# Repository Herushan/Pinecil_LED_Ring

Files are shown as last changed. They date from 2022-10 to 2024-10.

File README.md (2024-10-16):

# Pinecil_LED_Ring
Finished board with ideal LED combination.
Finished on Pinecil V2

White boards are shown are with smaller holes and new design (November 2023) has larger holes with better spacing and have the two LED methods of assembly shown (can use SMD on the through hole pads as shown). The yellow board is 1st draft of 3 LED design that missed some PCB info.
White boards are final one with 3 SMD LEDs and one with ideal kitting 2 through hole and 1 SMD LED New updated wire connection holes that are oval and square (November 2023). 

LED ring attachment for the Pinecil V2 soldering iron (should work for V1 as well as it goes on the body)
Recommend looking at the pictures and details to the inital two LED writeup (Pinecil_LED_Ring_writeup.pdf) that is here in the GitHub. The square holes are negative and round is positive. Arrow points to negative or left looking at board with LED at bottom.
LED position

The board is all done in KiCad and the zip file is all you need to produce a board. 
The LED is a 3mm LED with a third LED that is 0805
The SMD resistor is an 0805 with hand soldering footprint
Updated with an 0805 LED on the bottom to help with shadowing.

Kit with all the parts.
Kit

Assembly of kit video (Video of soldering to Pinecil V2 coming later)
https://youtu.be/LMbjwjDbSew
Assembly to Pinecil
https://youtu.be/VbyIGmIXqKs

Calculate your resistor based on the LED you choose and the power source form the Pinecil you decide to use as well. Resistor should be around 75ohms with 3.2V forward voltage and 20 mA forward current on the LED.

Recommend soldering (being careful small gap and size to board holes) the power and ground with sold strand wire preferrably to the holes and to the iron. Wire should be small as 30/32 awg is currently what I am using but hole supports upto .015 inch wire which should be around 26 awg max.

***May not happen*** Will update to SPI controlled lights when a known SPI connection is possible. This might not come and optional mod to add switch for on/off control for those that do not want to always be on will be looked at. I actually find it always being on nice.

Recommend reading the wiki (https://wiki.pine64.org/wiki/Pinecil) for guides to opening the Pinecil (https://www.youtube.com/watch?v=aK01V5DrrVk).

The info on size of board according to Oshpark is: 2 layer board of 0.84 x 0.67 inches (21.2 x 17.1 mm)
Any 3mm through hole LED will work.
SMD LED that works for the pad: https://www.digikey.com/en/products/detail/harvatek-corporation/B1701TX-20P000614U1930/16671745
Resistor that works: https://www.digikey.com/en/products/detail/rohm-semiconductor/ESR10EZPF75R0/1983560

Contact me on discord (@ahall(RuShan)) on the Pine64 channel for any questions through DM is fine.
If you would like to use my referral link to elecrow for boards: https://www.elecrow.com/referral-program/MTM5NjdqMnQ/

I also shared the project on Elecrow here: https://www.elecrow.com/sharepj/pinecil-led-ring-add-on-358.html

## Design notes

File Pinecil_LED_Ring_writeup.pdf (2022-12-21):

My name is Andrew and I am @ahall#7894 on the discord or @rushan_ee on twitter. My github for this project is here: Herushan/Pinecil_LED_Ring: LED ring attachment for the Pinecil V2 soldering iron (should work for V1 as well as it goes on the body) (github.com) (https://github.com/Herushan/Pinecil_LED_Ring)

This project of making a LED ring for the Pinecil soldering iron came when we talked about a project on the pine64 forum of a project dzid26 did with adding lights to the Pinecil. Started talking ideas and came up with a PCB design that I shared with the discord group and finally got to a style that most everyone liked.

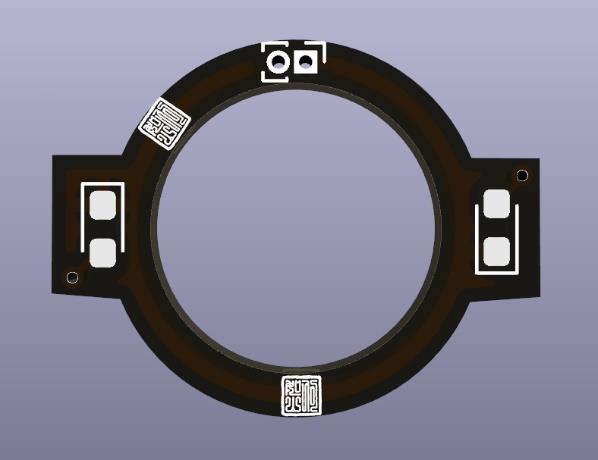
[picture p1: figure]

Figure 1. Original PCB draft design with SMD LEDs.

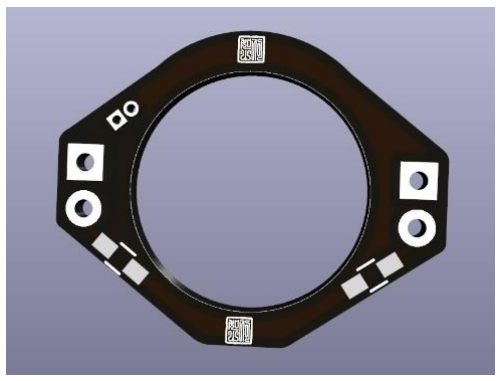
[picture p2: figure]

Figure 2. Final design for prototypes with through hole LEDs and SMD resistors.

Once I got the design finished in KiCad that looked acceptable and after making sure all the dimensions worked with the Pinecil.

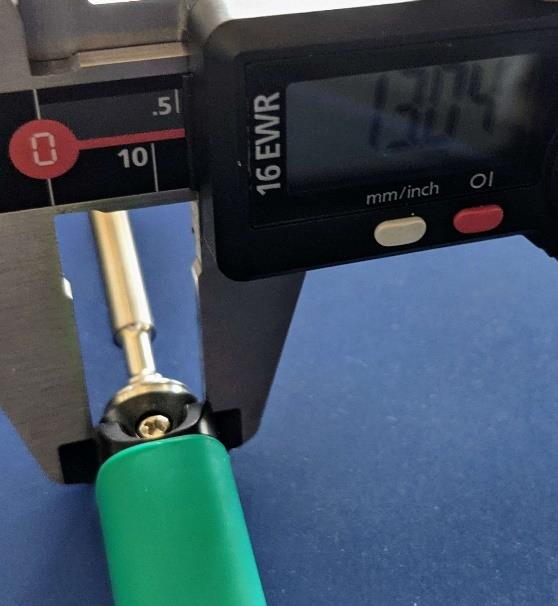
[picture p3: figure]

Figure 3. Width of plastic area for LED Ring to be snug on.

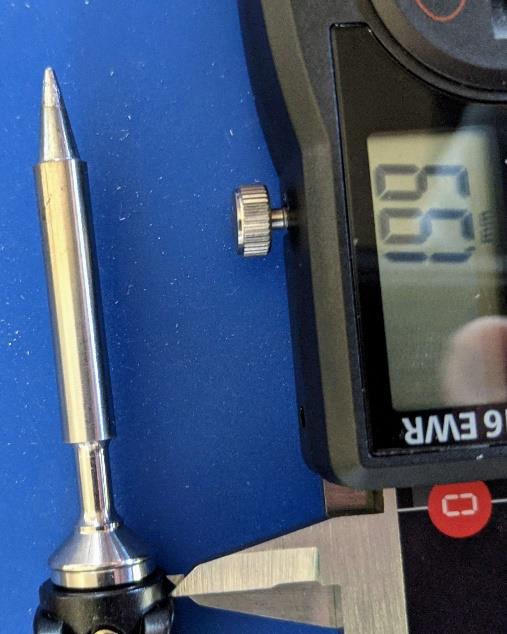
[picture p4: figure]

When I got the board complete to measurements I put them out on my github site for others to look at if they wanted to. One of the discord members that use another service through the bot “oko_123” was kind enough to take the gerber file and do a 3D print of the board to make sure my measurements worked before I ordered prototypes of the board.

Figure 4. Verify that 1.6mm PCB will fit on ring and allow screw to work (if you use a thumb screw).

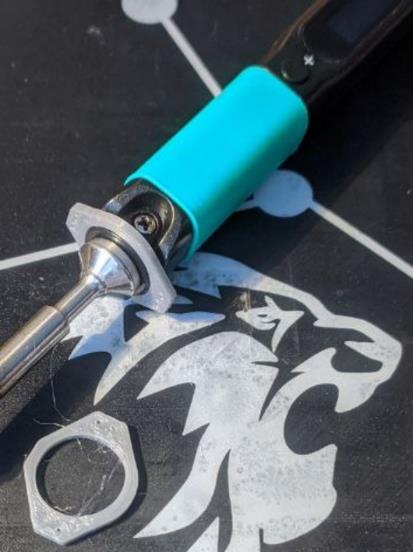
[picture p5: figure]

Figure 5. 3D print picture from oko_123 of the LED Ring design.

I ordered prototypes through Oshpark here in the US in their afterdark option as I wanted something cool looking. This option took some time but was worth it when they finally came in and I got to see them. Oshpark does not remove the bites from the board so I had to do some sanding to make them look nice and then to check how close they came to my design dimensions.

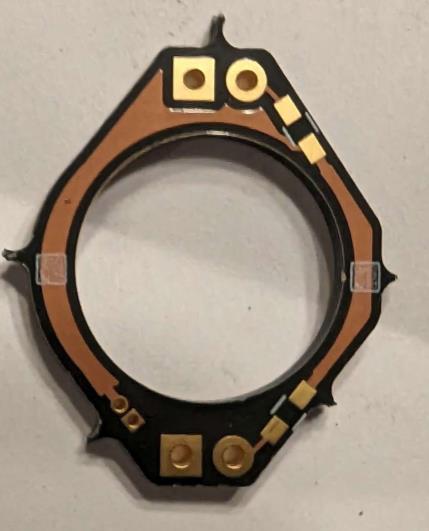
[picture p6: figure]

Once sanded and and measured the middle hole was about .05 mm too small which took just a few passes of the Dremel sander to get to snug fit on the Pinecil which is perfect. The end result once the resistors and LEDs were put on that I had on hand which were not quite what I needed with values on the resistors ended up working great.

Figure 6. Prototype straight from board house before sanding

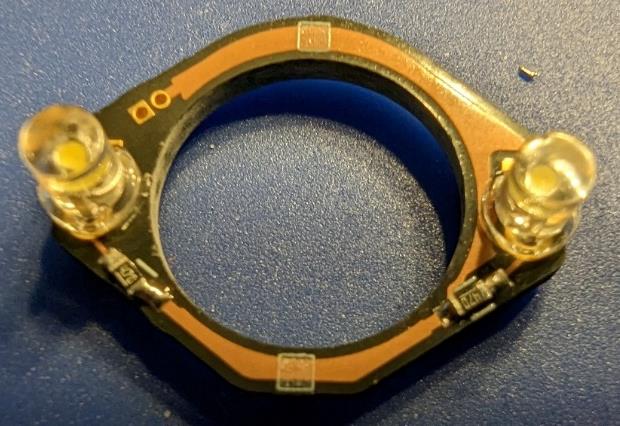
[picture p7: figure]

Figure 7. LED Ring cleaned up and parts soldered on.

The size of the power and GND holes can fit about wire up to ~.015 inches or .4mm in size. I used some 32-gauge wire I had which works great and allows for minor cutting of the shell to get the wires through.

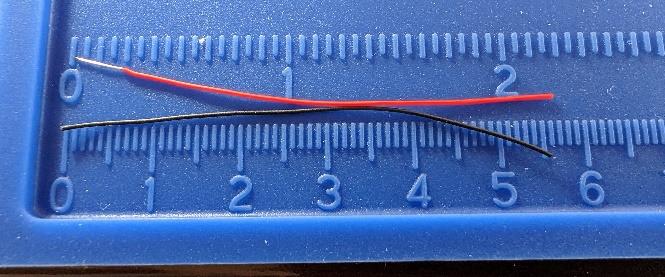
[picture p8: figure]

With the early discussion on the discord, it was determined that the 4.X volt source would be best and not to use the 3.3V on U10 that is missing on the V2 of the Pinecil. This led to pulling power of the C8 and L1 junction which the side of C8 is best to do from and using any ground source which I used pin 5 pad for U10 on my Pinecil V2.

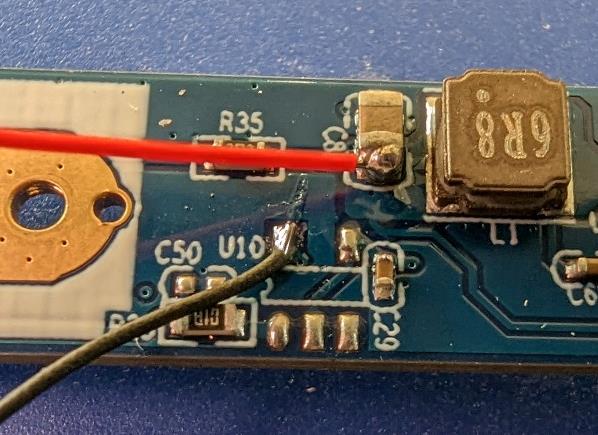
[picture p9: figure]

With the power source soldered it was time to figure out the exit point for the wires to the LED Ring and you want some slack in the wires so you can still disassemble the iron if you need to.

Figure 8. Power wires used for LED Ring prototype.

Figure 9. Source points for powering LED Ring.

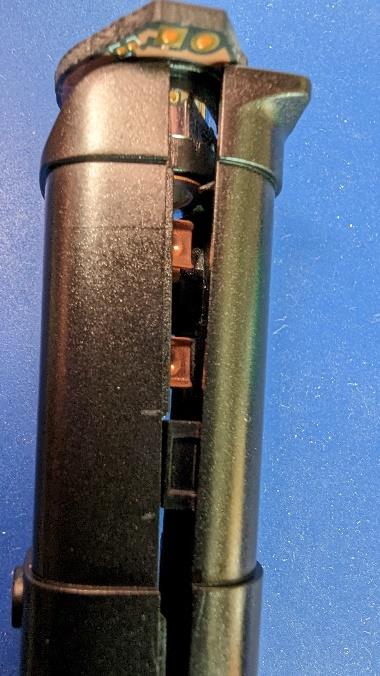
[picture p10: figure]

Figure 10. Side slightly open on Pinecil to see where tabs are.

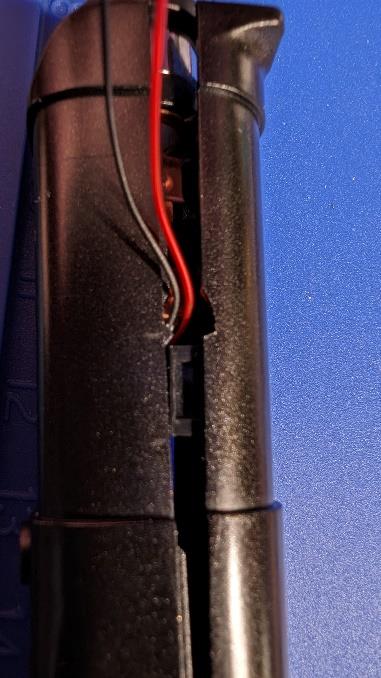
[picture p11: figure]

Figure 11. Where I decided to cut a small hole for wires to go through.

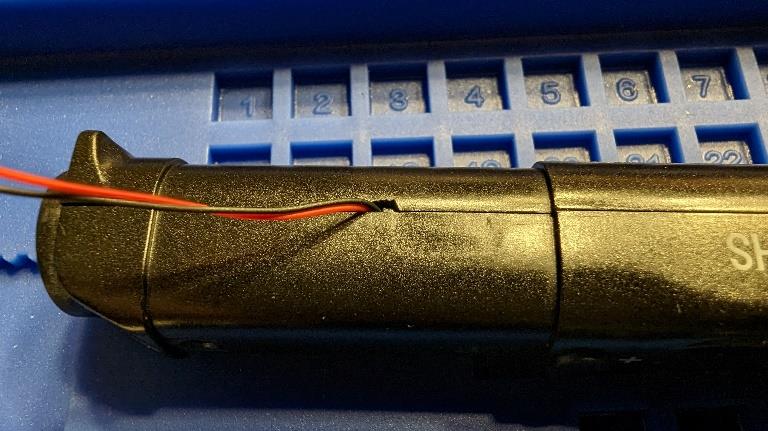
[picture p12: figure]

Figure 12. How it looks when closed again.

I decided to exit right before the first clip and under the grip of the iron as the wires are small and do not produce any odd feeling. Can do it farther forward and secure wires to side of iron so they do not get too close to the tip contact points as well.

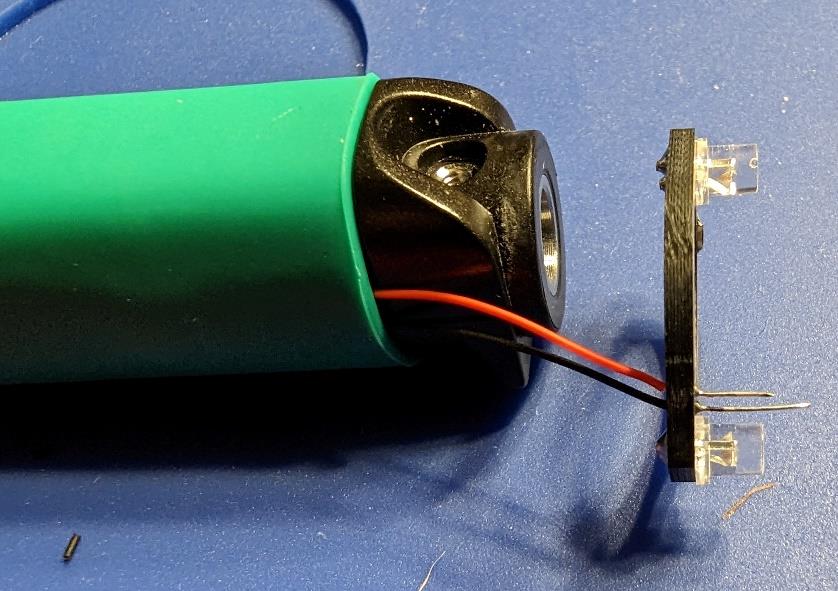
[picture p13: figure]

After soldering on the power wires and this is where I wish I added an on/off switch as the lights are always on with the iron at this point. I trimmed the excess wire and put the ring on the tip and tested it out.

Figure 13. Attaching LED Ring to power wires.

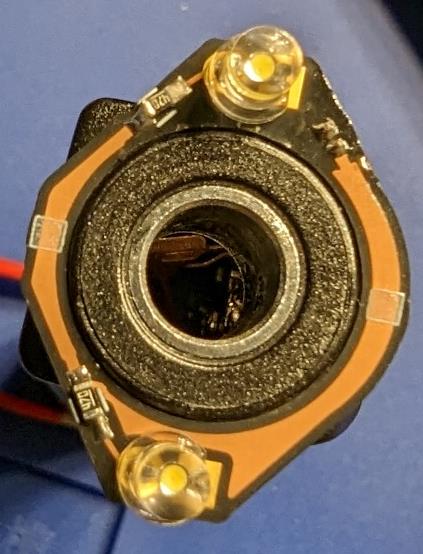
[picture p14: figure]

Figure 14. Top view of LED ring on iron with no tip installed.

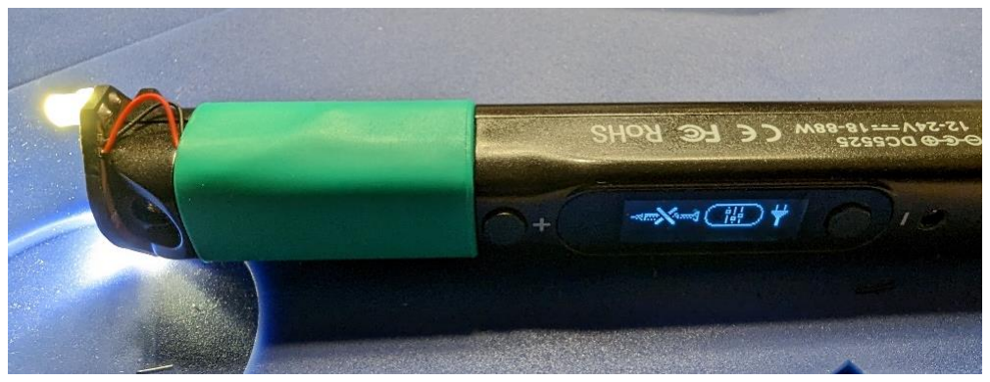
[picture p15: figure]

Figure 15. Fully installed without tip or tip retention screw and powered on with iron.

Now that I know the LED ring works, I put the iron tip in and did the aftermarket thumbscrew to make sure it still worked with no issues and have soldered a few hours now with it with no issues. I have some other images showing how the LED ring looks.

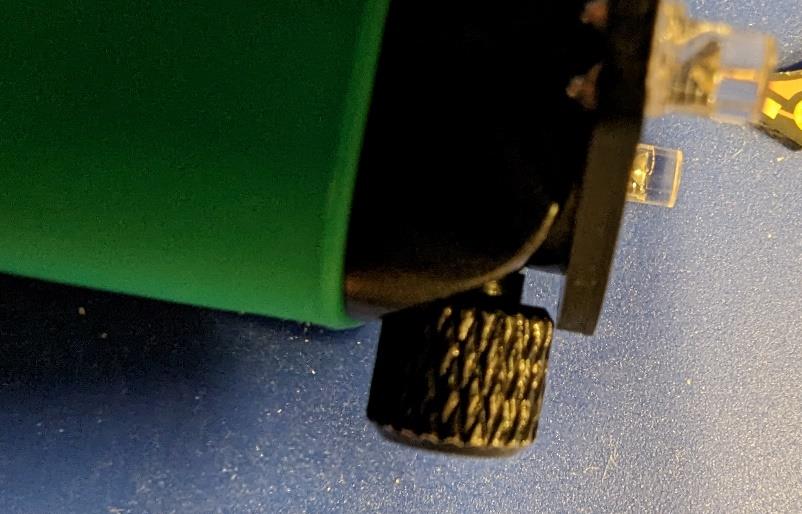
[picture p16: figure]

Figure 16. Close clearance between aftermarket thumbscrew and LED ring.

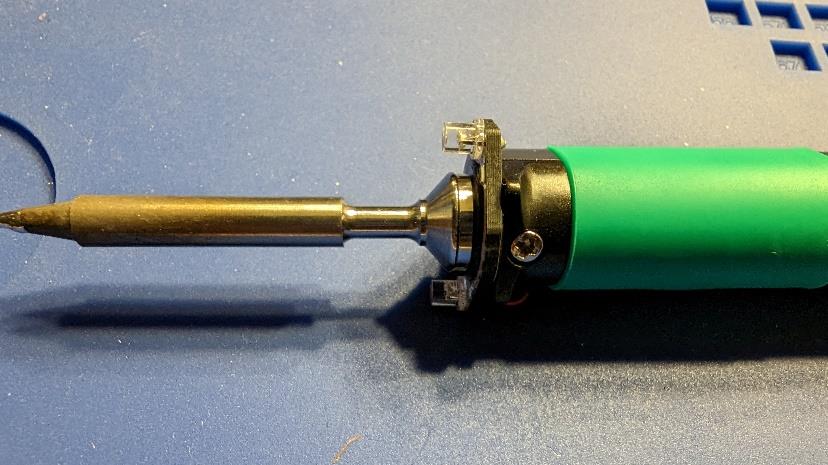
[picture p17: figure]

Figure 17. LED Ring on iron with tip not on.

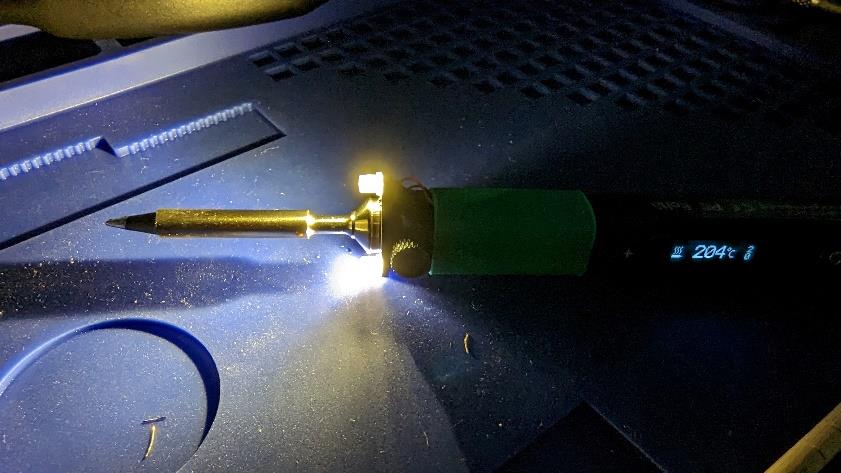
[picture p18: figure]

Figure 18. LED Ring on iron when on.

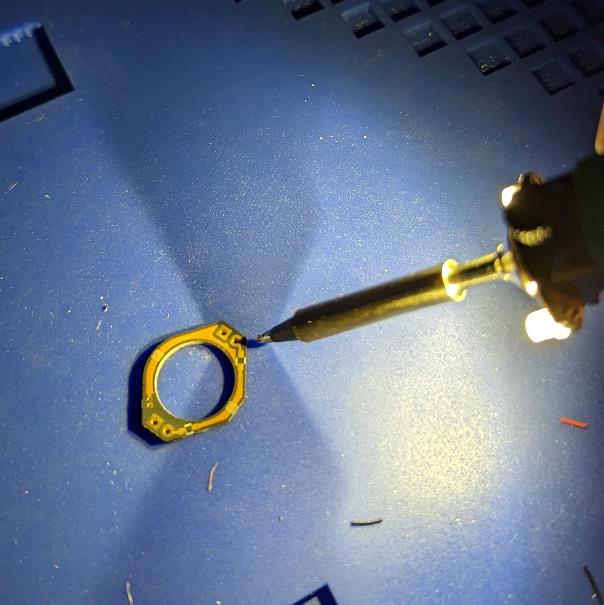
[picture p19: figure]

Figure 19. Holding iron with LED ring and noticed some shadowing with tip from lights in a dark room.

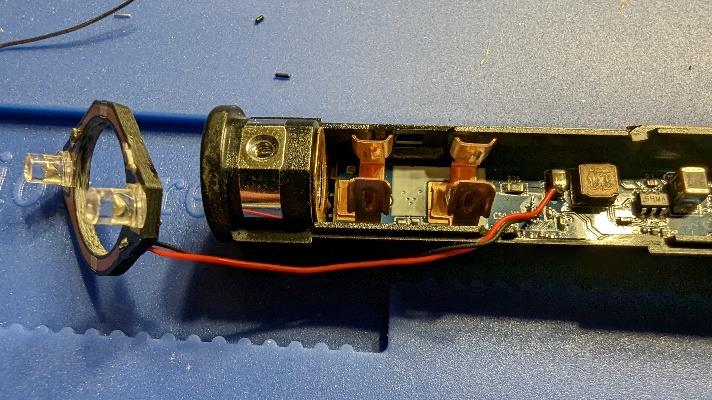
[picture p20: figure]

Figure 20. Slack with wires so you can still disassemble and assemble with LED ring attached.

The LED ring light prototyped turned out great and is small and effective for its purpose. Some want to see a SMD LED version and if it is possible to have an on/off switch as well. Looking at some options and updates to this design but as is it works well and is a viable lighting option for the Pinecil.

WARNINGS:

❖ This will void your warranty for the pinecil and you need to make sure the iron is not plugged in when soldering the power connections to the Pinecil board or the LED Ring.
❖ The voltage is 4.6 Volts for the power supply so most 3-3.2V LEDs will need around 75 ohm resistor to properly work.
❖ This version uses 3mm LEDs and 0603 sized SMD resistors.
❖ Putting conformal coating or clear nail polish over power/all solder joints on ring is
recommended to prevent accidental shorting.
❖ Current design powers on/off with iron so no independent on/off switch. -looking at adding one but hard with keeping small size of lights.
❖ Lights do cast shadow with tip and looking at ways to minimize the effect but not a big issue for me (could maybe angle lights instead of flush mount to PCB).
❖ SMD can work at the 0805 Size with the through hole pads.
❖ Some thumb screws may not work with this modification.
❖ If you do this on V1 you would have to solder GND wire for LED light ring to pad 5 of U10 chip (GND pin of chip).

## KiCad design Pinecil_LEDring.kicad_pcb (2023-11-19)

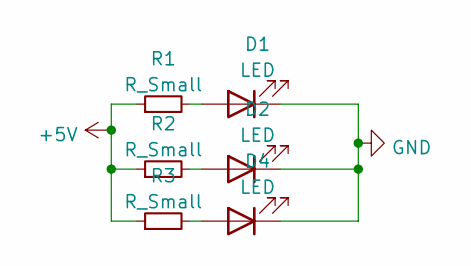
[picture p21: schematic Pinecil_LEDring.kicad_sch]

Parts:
D1, D2: LED; LED-3MM
D4: LED; LED_0805_2012Metric_Pad1.15x1.40mm_HandSolder
R1, R2, R3: R_Small; R_0603_HandSoldering

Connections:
+5V: R1.1, R2.1, R3.1
GND: D1.1 (K), D2.1 (K), D4.1 (K)
unnamed: D1.2 (A), R1.2
unnamed: D2.2 (A), R2.2
unnamed: D4.2 (A), R3.2

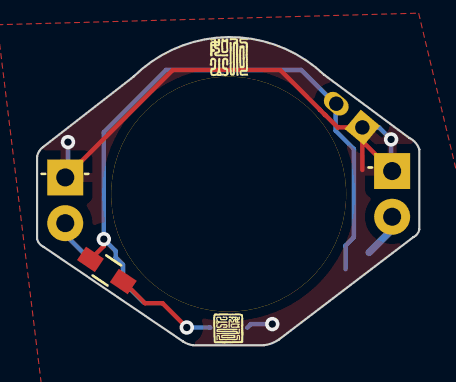
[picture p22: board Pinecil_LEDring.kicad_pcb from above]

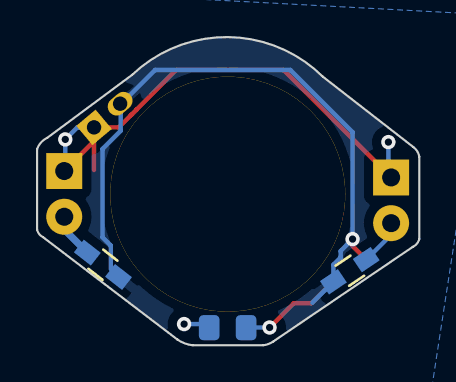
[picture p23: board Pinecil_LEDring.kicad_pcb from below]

Board: 2 copper layers, 21.2 x 17.1 mm, 7 parts (3 on the bottom side), 5 nets.

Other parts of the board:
Pinecil LED Ring: Pinecil_LEDring

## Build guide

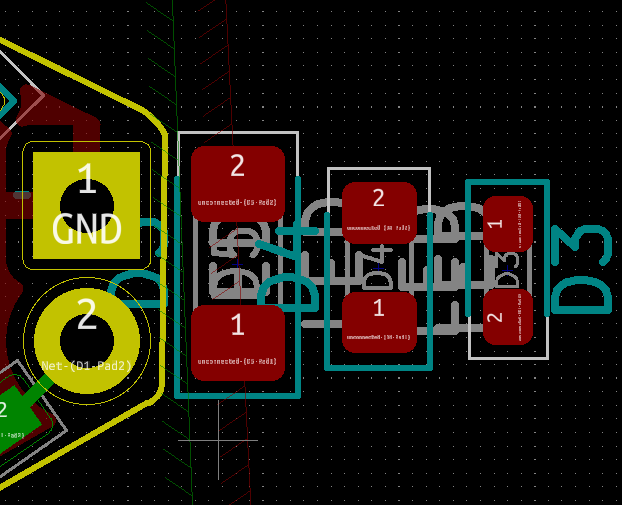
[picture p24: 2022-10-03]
SMDresistor_sizeguide_PinecilLight.png

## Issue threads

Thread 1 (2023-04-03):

photo of complete project

River-Mochi, 2023-04-03:
suggest at the very top of readme add a nice photo of a completed  LED ring so they can see what they get if they read rest of the article.
one photo off so people can see it and one photo on (side by side).

Herushan, 2023-04-03:
Added pictures and link to assembly of board components to the readme.

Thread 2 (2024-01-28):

Sorry to use this to communicate

SoLongSidekick, 2024-01-28:
I don't have a twitter or discord, I hope this is ok.

I'm just wondering why you didn't go full surface mount for the Pinecil LED ring? I was gonna modify the PCB to do it myself but figured there might have been a reason and that I should ask. When I saw that there is a space for a single surface mount LED on the board I got really confused as to why there was one but not all.

Secondarily any chance you have any PCBs still laying around? I can make them myself with pre-sensitized copper clad and either my laser cutter or SLA 3D printer but would rather have an OSHPark one if there's still one laying around. I'd also be interested in buying a hall effect chip or thumbscrew if you have any extras as well.

Thanks for all the work, freaking awesome mod!

Herushan, 2024-01-28:
You ask a good question that I probably need to verify that the information why is well documented on why I prefer the through hole LEDs on the side instead of SMD. First I want to point out that the through hole pads are done in a way that SMD LEDs can be mounted to them without issue as I did that when prototyping and testing what is best. The testing showed that SMD LEDs did not focus the light as well to the soldering area as the through hole options and is not as effective in the lights purpose. The one SMD on the bottom gives the right amount of flood light and keeps the shadowing down caused by the tip. I could not do a through hole on the bottom in keeping the minimalist design. Feel free to use the same size SMD as the bottom for the sides if you would like.

I do have sets available and do not charge a lot as I want to see people enjoy the mod. If you just want the PCB I can do that as well. I have a KoFi page and am on LinkedIn and Reddit as well for DMs to work details.

Closed 2024-02-01.

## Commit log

2022-12-21 Add files via upload
    Original 2 LED ring write up.
2023-04-03 Delete Pinecil_LEDring_Back_nontip.png
    Old 2 LED image
2023-04-03 Delete Pinecil_LEDring_Front_nontip.png
    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
2023-11-19 Added updated design files and gerbers
    Updated the design off the board to make soldering the wires easier.
    [Pinecil_LEDring-B_Cu.gbr, Pinecil_LEDring-B_Mask.gbr, Pinecil_LEDring-B_Paste.gbr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]
